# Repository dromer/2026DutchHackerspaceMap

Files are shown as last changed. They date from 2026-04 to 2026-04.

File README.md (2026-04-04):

# 2026 Dutch Hackerspace map

## General

This project was created for a soldering workshop held during International Open Hackespace Day 2026  (March 28th)  at techinc.nl, one of the Dutch hackerspaces. During preparations for this workshop it was discovered that another Dutch hacker space (revspace.nl) had previously also made an electronic map ("project decenium") for their 10th aniversery.

This Repository contains three directories:
- Hardware - with the KiCAD design files of the PCB
- Software - The software that runs on the map
- 3D - Design files for case(s) to hold the PCB
- Workshop - Instruction materials (crude) for the workshop

In it's basic form the map is a PCB with 18 2020 size ws2812 compatibe RGB LEDs on the front (representing the hackerspaces in NL), 6 capacitors and an ESP32C3 "supermini" module on the back. The ESP32 is retreiving information to drive the LEDs in specific colors: green when the space-state indicates the space is open, red when it is closed, blue when there is an (intermittant) communication issue, white when booting and a few other colours (not observed yet) indicating various rare conditions. The colours shown by the LEDs are animated

The PCB design lacks solder mask and copper outside the land boundaries of NL, showing the PCB base material, which is somewhat translucent. This can be used to mount a backlight behind the PCB. This backlight can either be a simple backlight or a 20 LED piece of common ws2812B LED strip. In the latter case it can be driven by the ESP32 as well.

## Hardware

The "hardware" folder contains the schematic diagram and KiCAD source files for this project. You should be able to produce gerber files, which can be processed into actual PCBs by any board house

IMPORTANT NOTICE
Please leave pin d9 of the ESP32C3 module disconnected. This is the boot mode selection pin, and connecting it to DO of the last WS281b will result in the ESP32 reliably booting into software upload mode - rendering the system non-functional. You can remove or cut the D9 pin from the module before soldering it onto the PCB or you can cut the trace leading to it from the last LED. If you want to use WS2812b based led strip as a backlight, then the DI pin of the led strip should be connected to the DO pin of the last LED - so either the PAD underneath the D9 pin of the ESP32 or the trace leading to it. THIS PROBLEM MAY BE FIXED IN NEW RELEASES OF THE HARDWARE

## Software

The "software" folder contains a self-contained Arduino application.

## Installing and compiling

As Espressif regulary makes breaking changes to their API, it is important that you use the __correct version of the Espressif framework for Arduino: 3.1.3__

After you have installed the Espressif board manager package, you can __select the "ESP32-C3 Dev-module"__, which is compatible with the ESP32-C3 "super-mini" module that is usedin this project.

Please make sure that you have __set the option "USB CDC enable on boot" to "enabled"__ (Arduino tools menu), and that you have selected the correct serial device. You may have to press and hold the boot-button while presssing and releasing the reset button to put the module into "upload mode".

.
### Notes on driving the LEDs with the "RMT" (remote control) perhipheral

The  "RMT" perhipheral.Can generate very accurately timed signals, and is Espressif's way of driving WS2812 LEDs. Unfortunately it has enormous memory overhead: it requires 32 times more storage than there is raw data to be sent to the LEDs. 24 bits to be sent to each LED requires 768 bits of memory. Every RGB byte translates to 8 32 bit word accesses. This method uses DMA (Direct memory access) to relieve the processor of these duties: The processor just needs to prepare a block of data and then start the transfer.

### Notes on driving the display with the "SPI" (synchronous serial port) perhipheral 

This program uses the "SPI" perhipheral. Signals are less accuratly timed, but do actually work with the types of LEDs tested so far. Overhead is much lower than for the "RMT" method: it requires 4 times more storage than there is raw data to be sent to the LEDs. 24 bits to be sent to each LED requires 96 bits of memory. Moreover, as every (RGB) byte access becomes a single 32 bit word access, processor overhead is relatively limited. This method uses DMA (Direct memory access) to relieve the processor of these duties: The processor just needs to prepare a block of data and then start the transfer.

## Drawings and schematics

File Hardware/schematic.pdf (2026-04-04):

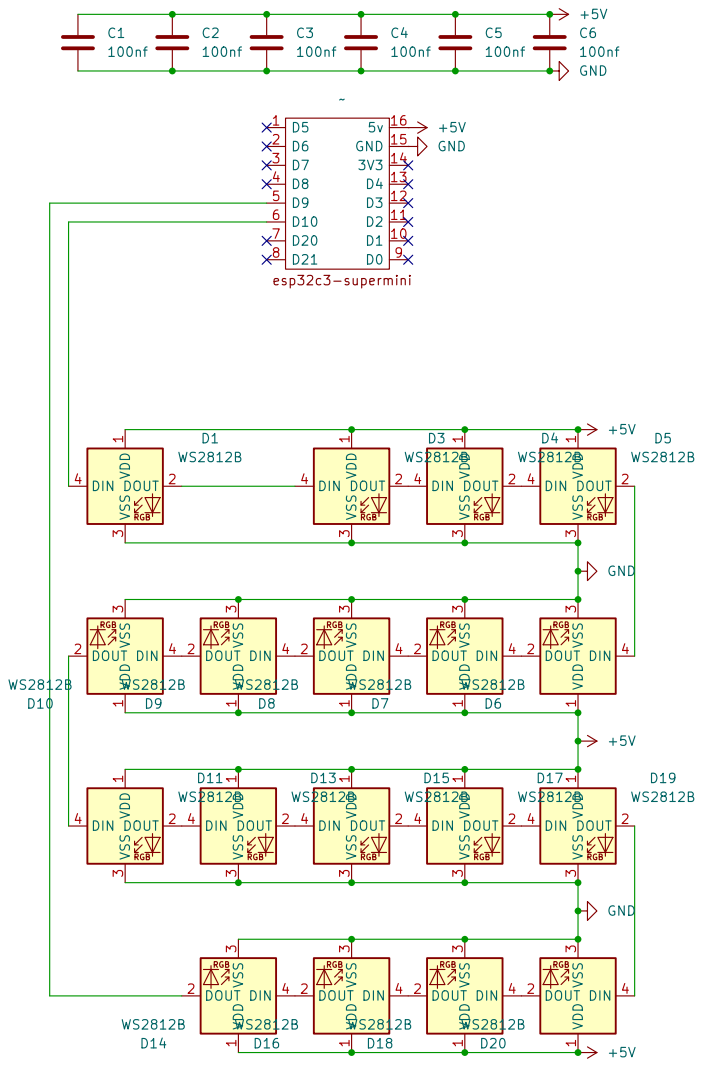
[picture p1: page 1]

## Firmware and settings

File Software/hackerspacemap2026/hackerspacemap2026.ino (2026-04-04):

/**********************************************************************************
 * Copyright (c) 2026, Theo Borm
 * 
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
 * 3. Neither the name of the copyright holder nor the names of its
 *    contributors may be used to endorse or promote products derived from
 *    this software without specific prior written permission.
 *
 * THIS SOFTWARE IS PROVIDED BY THE COPYRIGHT HOLDERS AND CONTRIBUTORS "AS IS"
 * AND ANY EXPRESS OR IMPLIED WARRANTIES, INCLUDING, BUT NOT LIMITED TO, THE
 * IMPLIED WARRANTIES OF MERCHANTABILITY AND FITNESS FOR A PARTICULAR PURPOSE ARE
 * DISCLAIMED. IN NO EVENT SHALL THE COPYRIGHT HOLDER OR CONTRIBUTORS BE LIABLE
 * FOR ANY DIRECT, INDIRECT, INCIDENTAL, SPECIAL, EXEMPLARY, OR CONSEQUENTIAL
 * DAMAGES (INCLUDING, BUT NOT LIMITED TO, PROCUREMENT OF SUBSTITUTE GOODS OR
 * SERVICES; LOSS OF USE, DATA, OR PROFITS; OR BUSINESS INTERRUPTION) HOWEVER
 * CAUSED AND ON ANY THEORY OF LIABILITY, WHETHER IN CONTRACT, STRICT LIABILITY,
 * OR TORT (INCLUDING NEGLIGENCE OR OTHERWISE) ARISING IN ANY WAY OUT OF THE USE
 * OF THIS SOFTWARE, EVEN IF ADVISED OF THE POSSIBILITY OF SUCH DAMAGE.
 */

// FOR WIFI CREDENTIALS SEE SETUP ROUTINE
// should fix this by setting up an access point an letting user enter their wifi credentials instead of this hack

/*******************************************************************************************************************
* Arduino sucks.
*
* Really, The Arduino IDE is a multi-level clusterfuck for everything but the simplest projects.
*
* This could (or maybe should) be a multi-page rant about what is wrong with ARDUINO, and there
* might be some entertainment value in that, but I simply don't have the time for it, so I'll
* be short.
*
* There is NO project management in ARDUINO, and if you split source across multiple files
* you end up in dependency hell because the ARDUINO IDE breaks C/C++ programming standards.
* Splitting complex source into multiple units along functional bounfaries is a way to keep
* code understandable and manageable, and is something programmers deal with on a daily basis.
* Not in ARDUINO IDE, though. The ARDUINO IDE adds some "Magic" to the compilation process which
* (I guess) makes it slightly easier to get started, but which breaks normal dependency management.
*
* While it may very well be possible to work around the limitations and create a multi-source-
* file project, with sources split in a way that makes some sense from a software maintainance
* point of view, I simply don't have the time nor energy to jump through these hoops, So I
* restructured everything so that it at least works: one big file.
*
*******************************************************************************************************************/



/* This map of hackerspaces in NL displays info about the open/closed state obtained INDIRECTLY through the
* SpaceAPI. There is no guarantee whatsoever that this  information is accurate. The necessary information is
* obtained by a server once every ~minute, compacted and presented as a single string - one ASCII character per
* hackerspace at the URL https://hackwinkel.nl/hsm2026/api
* The ASCII code of each character in the string is obtained by adding 32 to a 6 bit number encoding
* the colour of the corresponding LED. The following 6 bit binary RGB colours, numbers, ASCII codes and
* meanings are currently defined:
* 0b000000   0 -> 32=" " black   defunct space
* 0b110000  48 -> 80="P" red     closed
* 0b001100  12 -> 44="," green   open
* 0b101000  40 -> 72="H" yellow  indeterminate - JSON contains state->open, but neither true nor false
* 0b010100  20 -> 52="4" brown  indeterminate - JSON contains state, but not state->open
* 0b000101  05 -> 37="%" magenta  indeterminate - JSON contains no state
* 0b000011  03 -> 35="#" blue    no JSON or SpaceAPI unreachable
*
* //https://directory.spaceapi.io/ is a list of spaceapi providers
* with state->open->true/false in a json structure
*
* The following is a (at time of writing) list of SpaceAPI URLs of  Dutch hackerspaces that the
* server uses to generate the string that is ret
* https://maakplek.nl/api/
* https://mqtt.hackerspace-drenthe.nl/spaceapi
* https://spaceapi.tkkrlab.nl/
* https://hack42.nl/spacestate/json.php
* https://state.hackerspacenijmegen.nl/state.json
* https://spaceapi.tdvenlo.nl/spaceapi.json
* https://ackspace.nl/spaceAPI/
* https://hackalot.nl/statejson
* https://services.pi4dec.nl/space/spaceapi.json
* https://spaceapi.pixelbar.nl/
* https://revspace.nl/status/status.php
* https://portal.spaceleiden.nl/api/public/status.json
* http://techinc.nl/space/spacestate.json
* https://state.awesomespace.nl
* https://randomdata.sandervankasteel.nl/index.json
* https://hermithive.nl/state.json
* https://space.nurdspace.nl/spaceapi/status.json
* https://bitlair.nl/spaceapi.json
*
*/



/*******************************************************************************************************************
* INCLUDES section for external header files
*******************************************************************************************************************/
#include <Arduino.h>
#include <stdint.h>
#include <stdio.h>
#include <string.h>
#include "driver/spi_master.h"
#include "driver/gpio.h"
#include "esp_heap_caps.h"
// includes and objects for networking
#include <NetworkClientSecure.h>
#include <WiFi.h>
#include <esp_wifi.h>
#include "esp_mac.h"


/*******************************************************************************************************************
* TYPEDEFINITIONS section here because ARDUINO IDE does weird stuff with them
*******************************************************************************************************************/
// data needs to be stored in a special format to be able to send it to the LED string efficiently.
// this format is somewhat wasteful as it uses one 32 bit word per byte of information.
// struct holding the 3 32 bit encoded colour values in the required order. this struct represents one pixel
typedef struct {
  uint32_t G;
  uint32_t R;
  uint32_t B;
} SpiLedStringPixel;

// info about a hackerspace - state, led "phase" and "speed" - is stored in a structure for each space
typedef struct {
  uint8_t state;
  uint8_t phase;
  uint8_t speed;
  uint8_t count;
} SpaceInfo;

/*******************************************************************************************************************
* NETWORKING - CLIENT
*******************************************************************************************************************/
// FOR WIFI CREDENTIALS SEE SETUP ROUTINE
// should fix this by setting up an access point an letting user enter their wifi credentials instead of this hack

NetworkClientSecure client;
char ssid[40];
char password[40];

int16_t reconnect=false; // was the module ever connected?

const char *server = "hackwinkel.nl";
const char *path = "hsm2026/api";
char tempstr[100]; // for constructing strings

// try to (re-)connect to the wifi network, returns true on succes
void ConnectWifi(void) {
  if (reconnect) { WiFi.reconnect(); } else { WiFi.begin(ssid, password); }
}

int IsWifiConnected(void) {
    if (WiFi.status() == WL_CONNECTED) return(true); else return (false);
}

// try to get data from the server. wifi MUST be connected
int GetData(char * data, int maxlength) {
  int ok=true;
  data[0]=0; // clears out string
  if (WiFi.status() != WL_CONNECTED) { return(false); }
  //client.setCACert(rootCACertificate);
  client.setInsecure();
  if (!client.connect(server, 443)) {
    Serial.println("Failed to connect to server");
    return(false);
  } else {
    sprintf(tempstr,"GET https://%s/%s HTTP/1.1\r\n",server,path);
    client.print(tempstr);
    sprintf(tempstr,"Host: %s\r\n",server);
    client.print(tempstr);
    client.print("Connection: close\r\n\r\n");
    // simply ignore response headers
    while (client.connected()) {
      String line = client.readStringUntil('\n');
      if (line == "\r") {
        break;
      }
    }
    // get response content if available
    int cnt=0;
    while (client.available() && cnt<maxlength) {
      data[cnt] = client.read();
      cnt++;
      data[cnt] = 0; // zero terminate response
    }
    client.stop();
    if (cnt>0) return(true); // some content was obtained
  }
  return(false);
}


/*******************************************************************************************************************
* TIMER section - to maintain a 10 ms tick timer and tick flag and 60s tock timer and tock flag
*******************************************************************************************************************/
hw_timer_t * times = NULL; // a timer structure

uint32_t tick=0; // 10 ms each
uint32_t tickflag=0;
uint32_t tockticks=0; // 6000 ticks is one tock
uint32_t tock=0; // 60s each;
uint32_t tockflag=0;

void IRAM_ATTR HandleTimer(void) {
  tick++;
  tickflag=1;
  tockticks++;
  if (tockticks>=6000) {
    tock++;
    tockticks=0;
    tockflag=1;
  }
}

int InitializeTimer(void) {
  times = timerBegin(1000000); // 1Mhz
  if (times == NULL) {
    return(false);
  } else {
    timerAttachInterrupt(times, &HandleTimer);
    timerAlarm(times, 10000, true, 0); // Alarm 10ms
    return(true);
  }
}

/*******************************************************************************************************************
* SPILEDSTRING section -  a basic SPI+DMA hardware LED string driver.
*******************************************************************************************************************/
#define LEDSTRINGPIN 10
#define LEDSTRINGSIZE 38 // 18 spaces + 20 backlight LEDs
/*
 * This code uses SPI to send data to the ws2812 LED(s).
 * The WS2812 expects each bit to last ~ 1.2 us. A "1" is transmitted as an 800ns
 * high level on a pin, followed by a 400ns low level. A "0" is transmitted as a 400ns
 * high level on a pin, followed by an 800ns low level. The data rate is 800 kbit/s
 * If we operate the SPI at 3.2 MHz, we can "emulate" this on-off pattern with 4 bits
 * per bit that must be sent to the panel. A "0" bit is emulated using the pattern
 * 1000, a "1" bit is emulated using the pattern 1110. This means that a "0" bit is
 * sent as a 312.5 ns high, followed by a 937.5 ns low signal, and that a "1" bit is
 * sent as a 837.5 ns high, followed by a 312.5 ns low signal. This is OFF-SPEC, but
 * it works. Main benefit is that one byte of data to be transmitted fits into a 32
 * bit pattern, using "only" 4 times more memory than the "real" data, as opposed to
 * 32 times as much data for the RMT perhipheral. This also makes manipulating
 * display data much more efficient. Instead of shifting colour bits and then turning
 * colour bits into 32 bits in memory, we can write a (translated) colour byte to
 * memory as a single 32 bit word.
 * It would be possible to reduce the memory consumption by a quarter by using patterns
 * of three bits per "0" or "1", but that would require a lot more processing and
 * memory transfer cycles.
 *
 * The RGB values must be encoded in 3 consecutive 32 bit words in the right (GRB)
 * order. Each bit of each RGB value byte must be translated in a 4 bit pattern. The
 * storage order of these patterns in the 32 bit words depends on the endianness of
 * the ESP32, and is (for each bit 0..7, with 7 the most significant in the byte):
 * 11110000333322225555444477776666
 *
 * This encoding is hanldled  by the SpiLedStringSetPixel() function, which calls the
 * SpiLedStringEncodeValue() function for each (R, G, B) value.
 */

//default #define for the pin to which the string is connected
#define LEDSTRINGBITS LEDSTRINGSIZE * 24 * 4

// encoded RGB string memory
DMA_ATTR SpiLedStringPixel ledDMAbuffer[LEDSTRINGSIZE];

// Encode an 8 bit value into a 32 bit value
uint32_t SpiLedStringEncodeValue(uint8_t v) {
  uint32_t r=0b10001000100010001000100010001000; //encoding of all zero bits
  if (v&  1) r |= 0b10001110100010001000100010001000;
  if (v&  2) r |= 0b11101000100010001000100010001000;
  if (v&  4) r |= 0b10001000100011101000100010001000;
  if (v&  8) r |= 0b10001000111010001000100010001000;
  if (v& 16) r |= 0b10001000100010001000111010001000;
  if (v& 32) r |= 0b10001000100010001110100010001000;
  if (v& 64) r |= 0b10001000100010001000100010001110;
  if (v&128) r |= 0b10001000100010001000100011101000;
  return(r);
 }

 // fill a single LED string pixel with the appropriate encoded values
  void SpiLedStringSetPixel(int p, uint8_t R, uint8_t G, uint8_t B) {
    ledDMAbuffer[p].R=SpiLedStringEncodeValue(R);
    ledDMAbuffer[p].G=SpiLedStringEncodeValue(G);
    ledDMAbuffer[p].B=SpiLedStringEncodeValue(B);
  }

// control structures for the spi interface attached to the led string
static spi_device_handle_t ledStringSpiDevice;
static spi_device_interface_config_t ledStringSpiInterfaceCfg;
static spi_bus_config_t ledStringSpiBusCfg;
static spi_transaction_t ledStringSpiTransaction;

// initialize the hardware to drive a led string
void SpiLedStringInitialize(void) {
  ledStringSpiBusCfg = {
  	.mosi_io_num = LEDSTRINGPIN,
  	.miso_io_num = -1,
  	.sclk_io_num = -1,
  	.quadwp_io_num = -1,
  	.quadhd_io_num = -1,
  	.max_transfer_sz = LEDSTRINGBITS
	};
  ledStringSpiInterfaceCfg = {
    .command_bits = 0,
    .address_bits = 0,
    .mode = 0,
    .clock_speed_hz = 3200000,
  	.spics_io_num = -1,
  	.queue_size = 1 
	};
  ledStringSpiTransaction = {
    .flags=0,
    .cmd=0,
    .addr=0,
    .length=LEDSTRINGBITS,// in bits
    .rxlength=0,
    .user=(void*)0,
    .tx_buffer=(void *)ledDMAbuffer,
    .rx_buffer=(void*)0
  };

	esp_err_t err;
	err = spi_bus_initialize(SPI2_HOST, &ledStringSpiBusCfg, SPI_DMA_CH_AUTO);
	ESP_ERROR_CHECK(err);
	err = spi_bus_add_device(SPI2_HOST, &ledStringSpiInterfaceCfg, &ledStringSpiDevice);
	ESP_ERROR_CHECK(err);
}

// update the actual screen by starting the data transfer
void SpiLedStringTransmit(void) {
  esp_err_t err;
  err = spi_device_queue_trans(ledStringSpiDevice, &ledStringSpiTransaction,1);
}

/*******************************************************************************************************************
* RENDERING and DISPLAY section -  hackerspace map specific
*******************************************************************************************************************/
/*
 * The led string is split in two parts: The first 18 LEDs are used to reflect the actual space states.
 * The (optional) other LEDs are used as a backlight to the PCB.
 *
 * The space state LEDs get their colors from 3 arrays: "states", "phases" and "speeds".
 * The "states" determine the colours of the LEDs, and are directly related to the reported space state.
 * The "phases" determine the brightness of the LEDs, and are used to impart a (sort of) "breathing" effect
 * The "speeds: determine the speed at which the "breathing" happens.
 *
 * the backlight will have half the LEDs show one colour and the other half the "oposite" colour.
 * the colour wil change slowly, and the halves will also rotate (more) slowly.
 * the current state of the backlight is therefore governed by two variables: blcol and blphase
 * bgcol is an index into two arrays of colour-values:
 * 0 -> 60,00,00 / 00,30,30
 * 1 -> 40,20,00 / 10,20,30
 * 2 -> 20,40,00 / 20,10,30
 * 3 -> 00,60,00 / 30,00,30
 * 4 -> 00,40,20 / 30,10,20
 * 5 -> 00,20,40 / 30,20,10
 * 6 -> 00,00,60 / 30,30,00
 * 7 -> 20,00,40 / 20,30,10
 * 8 -> 40,00,20 / 10,30,20
 */
uint32_t foreground[]={ 0x3c0000, 0x281400, 0x142800, 0x003c00, 0x002814, 0x001428, 0x00002c, 0x140028, 0x280014 };
uint32_t background[]={ 0x001e1e, 0x0a141e, 0x140a1e, 0x1e001e, 0x1e0a14, 0x1e1e0a, 0x1e1e00, 0x141e0a, 0x0a1e14 };
int blcol=0;
int blcolcount=0;
int blcolspeed=2353;
int blphase=0;
int blphasecount=0;
int blphasespeed=91;

 #define SPACELEDS 18
 #define BACKLIGHTLEDS 20

SpaceInfo Spaces[SPACELEDS]; ///stores info for the LED of each space

void ClearSpaceInfo(void) {
  for (int i=0; i<SPACELEDS; i++) {
    Spaces[i].state=21; // 64 possible values 0 is black
    Spaces[i].phase=0; // count from 0..30, corresponding to brightness 1..16..1
    Spaces[i].speed=7; // speed for updating phase
    Spaces[i].count=0; // counter for updating phase
  }
}

void FillSpaceInfo(char * d) {
  for (int i=0; i<SPACELEDS; i++) {
    int t=2;
    if ((d[i]-32)&48) t+=7;
    if ((d[i]-32)&12) t+=3;
    if ((d[i]-32)&3) t+=9;
    Spaces[i].state=d[i]-32; // 64 possible values 0 is black
    Spaces[i].speed=7+random(5); // speed for updating phase
    Spaces[i].count=Spaces[i].count % Spaces[i].speed; // counter for updating phase
  }

}
// takes the info from the space state and backlight and renders this info into SpiLedString DMA memory encoded as colors ready to be sent to the LEDs
// called every 10 ms
void Render(void) {
  for (int i=0; i<SPACELEDS; i++) {
    uint8_t brightness=Spaces[i].phase+1;
    if (brightness>16) brightness=32-brightness;
    SpiLedStringSetPixel(i, ((Spaces[i].state & 48)>>4)*brightness, ((Spaces[i].state & 12)>>2)*brightness, (Spaces[i].state & 3)*brightness);
  }
  for (int i=0; i<BACKLIGHTLEDS; i++) {
    int l=(i+blphase) % BACKLIGHTLEDS;
    if (l<(BACKLIGHTLEDS>>1)) {
      SpiLedStringSetPixel(SPACELEDS+i,(foreground[blcol]>>16)&0xff, (foreground[blcol]>>8)&0xff, (foreground[blcol])&0xff);
    } else {
     SpiLedStringSetPixel(SPACELEDS+i,(background[blcol]>>16)&0xff, (background[blcol]>>8)&0xff, (background[blcol])&0xff);
    }
  }
}

// update the states of the space LEDs and background. 
// called every 10 ms
void Update(void) {
  for (int i=0; i<SPACELEDS; i++) {
    Spaces[i].count++;
    if ((Spaces[i].count) >= (Spaces[i].speed)) {
      Spaces[i].count=0;
      int t=Spaces[i].phase+1;
      if (t>30) t=0;
      Spaces[i].phase=t;
    }
  }
  blphasecount++;
  if (blphasecount >= blphasespeed) {
    blphasecount=0;
    int t=blphase+1;
    if (t >= BACKLIGHTLEDS) t=0;
    blphase=t;
  }
  blcolcount++;
  if (blcolcount >= blcolspeed) {
    blcolcount=0;
    int t=blcol+1;
       if (t >= 9) t=0;
    blcol=t;
  }
}



int wifimode=0; // wifi unconfigured
uint32_t prev; // to timeout wifi stuff
uint32_t now;

void setup(void) {

  pinMode(8,OUTPUT); // attached to the ESP32 on-board LED - debugging wifi connection
  digitalWrite(8,HIGH); // wifi disconnected - LED on

  Serial.begin(115200);
  delay(100);
  Serial.println("Start");

  if (InitializeTimer()) {
    Serial.println("Timer started");
  } else {
     Serial.println("Timer failed to start");
  }
  SpiLedStringInitialize();
  Serial.println("LED string initialized");
  ClearSpaceInfo();


  strcpy(ssid,"mywifi"); // your default network SSID (name of wifi network)
  strcpy(password,"mywifipassword"); // your default network password

  ConnectWifi();

  prev=millis();
  now=prev;
  while (((now-prev)<15000) && (IsWifiConnected() == false) ) {
    delay(100);
    now=millis();
    digitalWrite(8,LOW);
  }

  if (IsWifiConnected()) {
    Serial.println("wifi is connected");
    digitalWrite(8,HIGH);
    wifimode=1;
  } else {
    Serial.println("wifi is NOT connected");
    digitalWrite(8,LOW);
    // maybe set up access point etc...
  }
}

int tockstate=0; // state machine

void loop(void) {
  if (tickflag) {
    Render();
    SpiLedStringTransmit();
    Update();
    tickflag=0;
    if (tockstate && wifimode) {
      switch (tockstate) {
        case 1:
          if (IsWifiConnected()) {
            tockstate=3;
          } else { 
            ConnectWifi();
            prev=millis();
            tockstate=2;
          }
          break;
        case 2:
          if (IsWifiConnected()) {
            digitalWrite(8,HIGH);
            tockstate=3; 
          } else {
              digitalWrite(8,LOW);
            now=millis();
            if ((now-prev) > 30000) {
              tockstate=0;
              Serial.println("WIFI timeout");
            }
          }
          break;
        case 3:
          char data[101];
          if (GetData(data,100)) {
            if (strlen(data) == SPACELEDS) {
              FillSpaceInfo(data);
            } else {
              Serial.println("incorrect data length");
            }
          } else {
            Serial.println("fail");
          }
          tockstate=0;
        break;
      }
    }
  }
  if (tockflag) {
    tockstate=1;
    Serial.println(tock);
    tockflag=0;
  }
}

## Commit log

2026-04-04 Initial commit for hardware design files
    [hackerspacemap.kicad_sch]
2026-04-04 added PDF schematic
